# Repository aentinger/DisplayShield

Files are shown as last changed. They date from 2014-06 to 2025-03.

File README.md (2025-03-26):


💾 Display Shield
=================



# 📸 Image

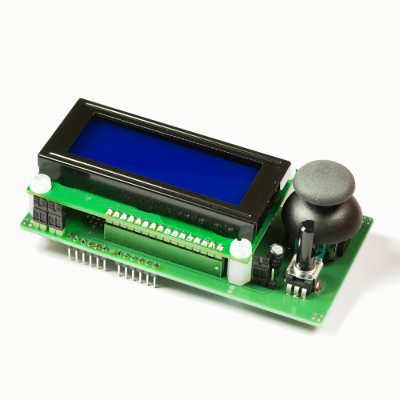
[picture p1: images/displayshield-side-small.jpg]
LXRobotics P10 DisplayShield


# 📂 Description

The LXRobotics Display Shield facilitates the easy control of a Liquid Crystal Display's with 4 rows and 20 columns. The control of the display is done via I2C - only two Arduino Pins are required. The contrast of LCD can be adjusted using a rotary potentiometer. A 2-axis joystick with integrated pushbutton can be used as input device. For a quick and easy start, an open source Arduino library with sample programs is available.

**Features**

* Large LCD (Liquid Crystal Display) with 4 rows und 20 columns [4x20] 
* LCD-font color: white
* LCD-background color: blue
* LCD included in scope of delivery
* Background illumination on/off switchable
* Display contrast is adjustable via a rotary potentiometer
* Control over I2C - only two Arduino-Pins are required (SDA, SCL)
* I2C-PullUp-Resistors can be connected via jumpers
* 2-axis joystick with integrated pushbutton
* Display Shield firmware is open source
* Microcontroller programmed with current firmware is included in assembly kit
* Display Shield Firmwareupdate via Arduino possible
* Arduino Library with example programs is available on GitHub

# 🎥 [Video](images/display_shield_demo.mp4)

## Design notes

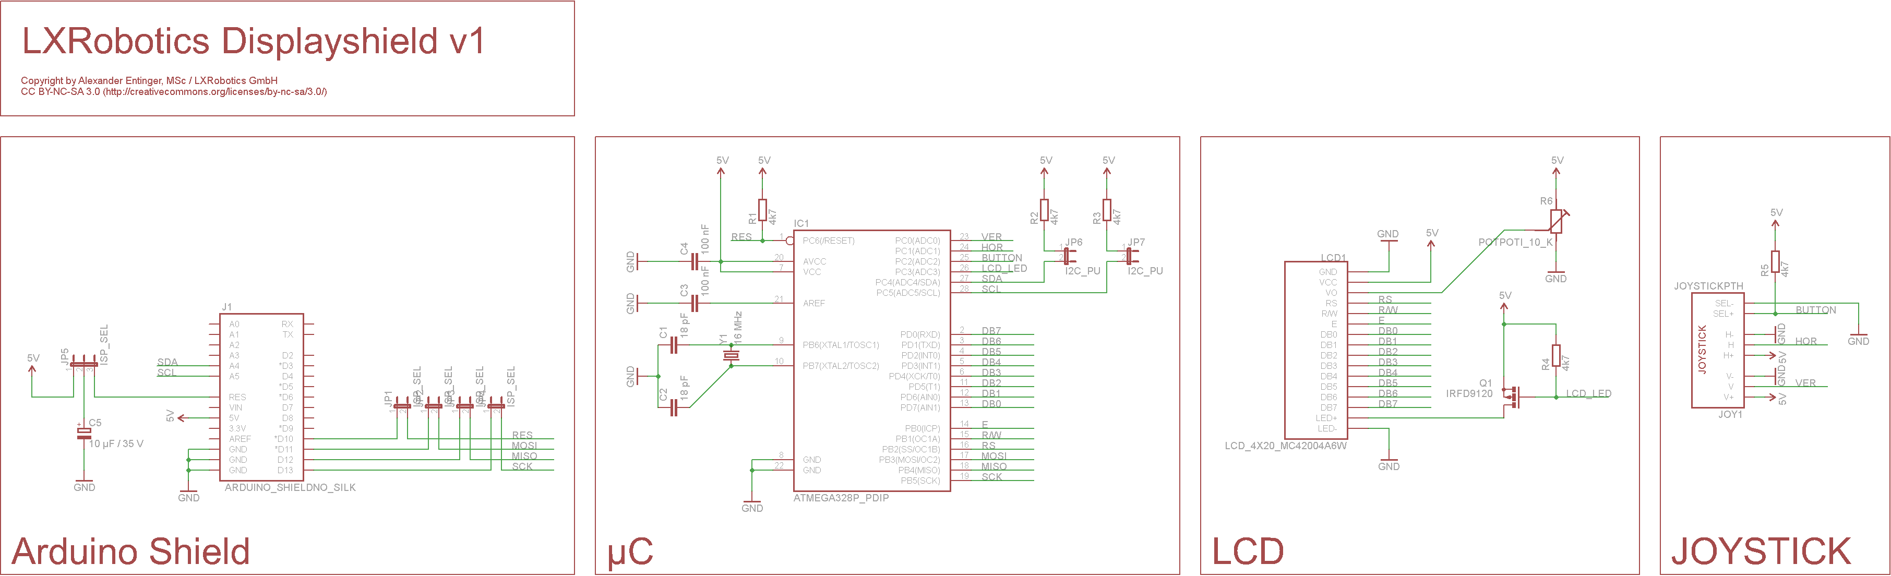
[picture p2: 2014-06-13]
hardware/lxr_display_shield_v1.png

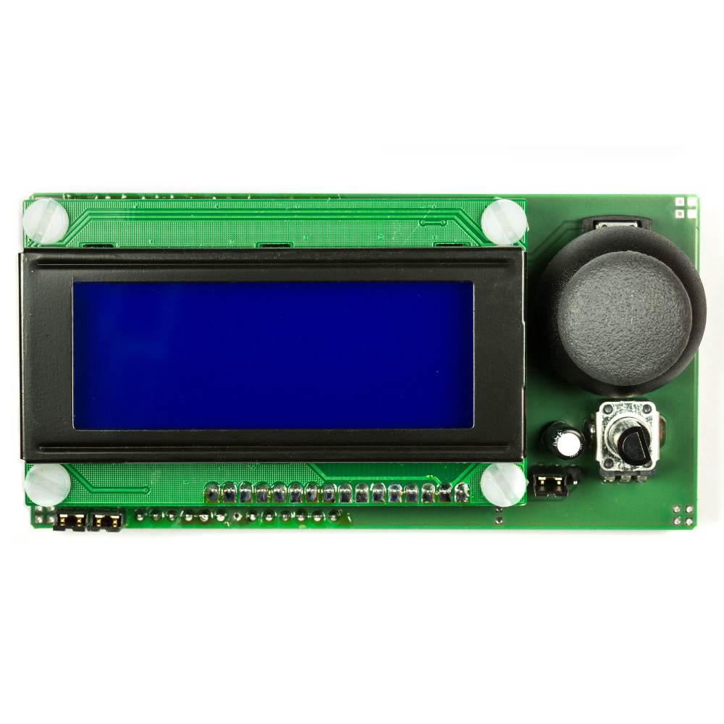
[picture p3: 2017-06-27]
images/displayshield-top-large.jpg

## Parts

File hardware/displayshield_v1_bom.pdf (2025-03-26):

Menge | Schaltplan | Bezeichnung | Farnell/Conrad Bestell Nummer | Preis (1 Stück) | Gesamtpreis | Wird bestückt | Footprint | Säckchen
1 | | LCD-Display, 4x20 | 2063162 | € 15,02 | € 15,02 | | | S1
1 | IC1 | ATMEGA328P, PDIP28 | 1715487 | € 3,11 | € 3,11 | | | S2
1 | | PDIP28 Sockel | 1103850 | € 1,15 | € 1,15 | | | S2
1 | Y1 | Quarz, 16 MHz, HC49 | 1611761 | € 0,23 | € 0,23 | | | S2
2 | C1,C2 | Kondensator, 18 pF, bedrahtet | 2332948 | € 0,34 | € 0,68 | | | S3
2 | C3,C4 | Kondensator, 100 nF, bedrahtet | 1216444 | € 0,10 | € 0,21 | | | S3
5 | R1,R2,R3,R4,R5 | Widerstand, bedrahtet, 4k7, 1/8 W | 1700245 | € 0,01 | € 0,05 | | | S3
6 | JP1,JP2,JP3,JP4,JP6,JP7 | Stiftleiste, 2 Polig, 2.54 mm | 3418285 | € 0,24 | € 1,44 | | | S4
7 | | Jumper, 2 Polig, 2.54 mm | 4218176 | € 0,14 | € 0,98 | | | S4
1 | C5 | Kondensator, 10µF, 35V, D 5mm, Raster 2 mm | 1236669 | € 0,07 | € 0,07 | | | S3
1 | JP5 | Stiftleiste, 3 Polig, 2.54 mm | 1022249 | € 0,19 | € 0,19 | | | S4
1 | Q1 | P-Kanal-MOSFET, DIL, IRFD9120 | 9103244 | € 1,21 | € 1,21 | | | S2
1 | JOY1 | Joystick, 2 Achsen | € | 3,40 | € | 3,40 | S1 | Kann auch von LXRobotics bereitgestellt werden | http://www.watterott.com/de/Thumb-Joystick - http://www.amazon.de/Buttons-Switches-Joysticks-COM-09032-Joystick/dp/B004QOOB10 - http://www.lipoly.de/index.php?main_page=product_info&products_id=103716 - http://www.hobbytronics.co.uk/thumb-joystick - https://www.sparkfun.com/products/9032
1 | | Stiftleiste, 1x16, 2.54 mm | 1248124 | € 1,51 | € 1,51 | S4
1 | LCD1 | Buchsenleiste, 1x16, 2.54 mm | 3419174 | € 1,51 | € 1,51 | S4
1 | R6 | Drehpotentiometer, 10k | 1191725 | € 2,79 | € 2,79 | S3
2 | J1 | Arduino Stiftleisten, 1x6, 2.54 mm | 1022255 | € 0,37 | € 0,74 | S4
2 | J1 | Arduino Stiftleisten, 1x8, 2.54 mm | 1022257 | € 0,19 | € 0,38 | S4
4 | Zylingerschraube, Nylon, M4 x 6 mm | 527678 | € | 0,04 | € | 0,15 | S5 | RS Components
4 | Nylon Sechskant Abstandshalter, M4 x M4, 10 mm | 382955 | € | 0,24 | € | 0,96 | S5 | RS Components
4 | Sechskantmutter, Nylon, M4 | 525717 | € | 0,10 | € | 0,42 | S5 | RS Components
1 | Leitfähiger Schaumstoff | 1687855 | € | 2,40 | € | 2,40 | - | Bestellung von 1 Stück für 50 Display Shields ausreichend
| | | Summe | | € | 38,59

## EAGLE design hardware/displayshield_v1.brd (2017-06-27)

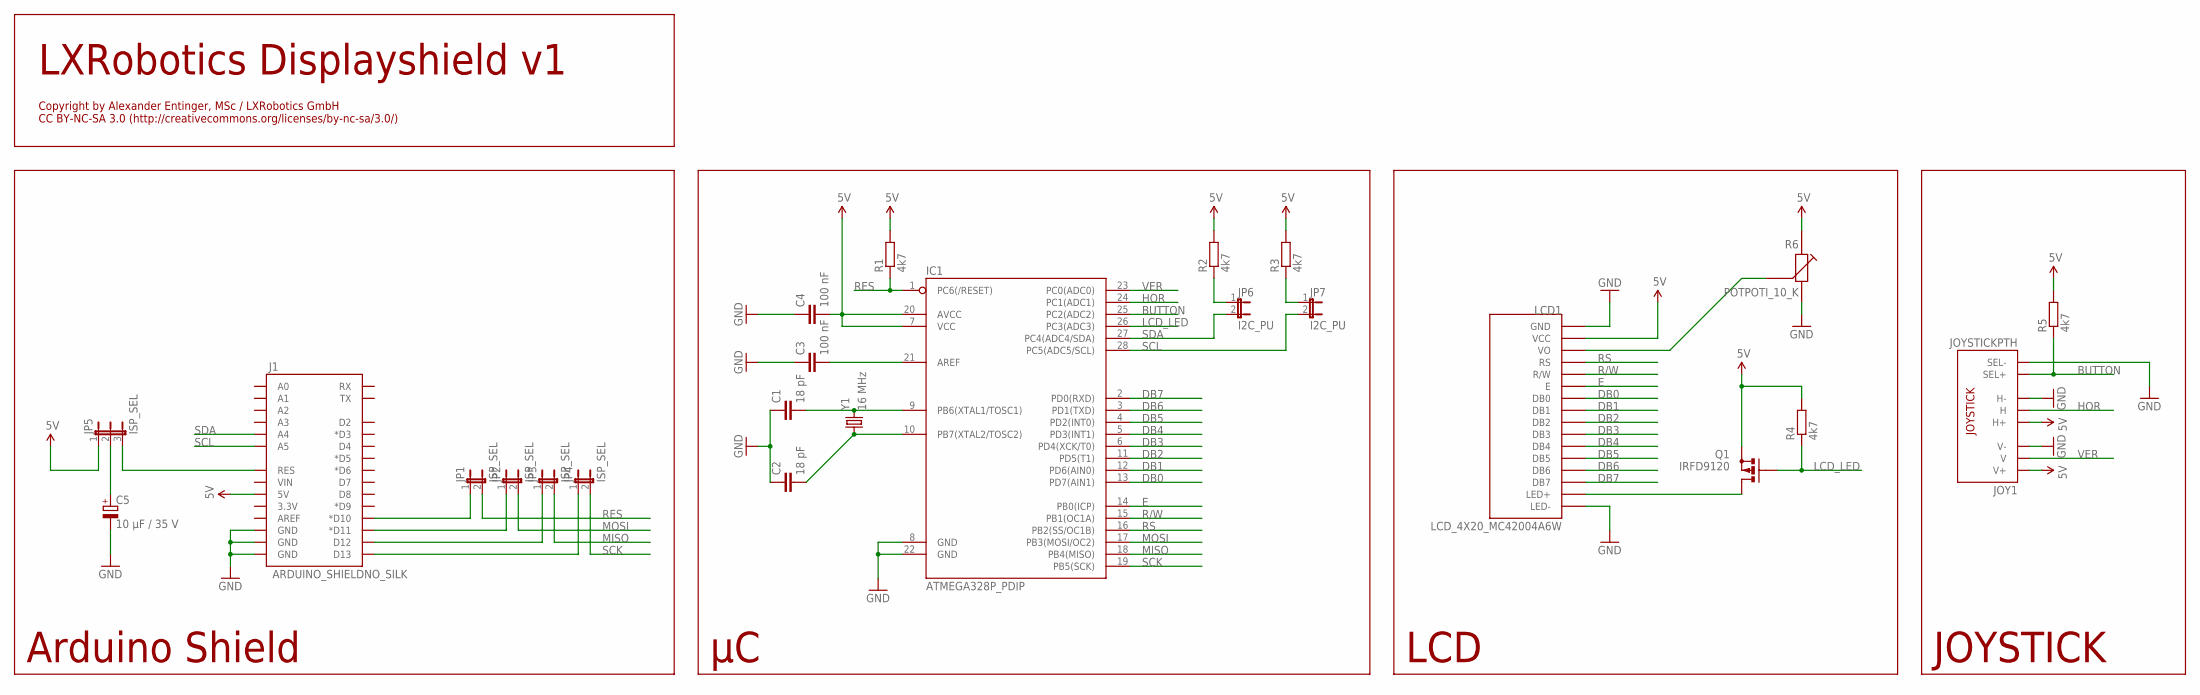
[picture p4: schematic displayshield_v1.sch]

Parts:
C1, C2: 18 pF; C025-025X050
C3, C4: 100 nF; C025-025X050
C5: 10 µF / 35 V; E2-5
IC1: ATMEGA328P_PDIP; DIL28-3
J1: ARDUINO_SHIELDNO_SILK; DUEMILANOVE_VIAS
JOY1: JOYSTICKPTH; JOYSTICK
JP1, JP2, JP3, JP4: ISP_SEL; JP1
JP5: ISP_SEL; JP2
JP6, JP7: I2C_PU; JP1
LCD1: LCD_4X20_MC42004A6W; LCD_3X40_MC42004A6W
Q1: IRFD9120; C370-01
R1, R2, R3, R4, R5: 4k7; 0204/5
R6: POTPOTI_10_K; POT_10K
Y1: 16 MHz; HC49US

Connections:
5V: C4.2, IC1.7 (VCC), IC1.20 (AVCC), J1.5V, JOY1.H1 (H+), JOY1.V1 (V+), JP5.1, LCD1.VCC, Q1.S, R1.2, R2.2, R3.2, R4.2, R5.2, R6.S
BUTTON: IC1.25 (PC2(ADC2)), JOY1.B1A (SEL+), R5.1
DB0: IC1.13 (PD7(AIN1)), LCD1.DB0
DB1: IC1.12 (PD6(AIN0)), LCD1.DB1
DB2: IC1.11 (PD5(T1)), LCD1.DB2
DB3: IC1.6 (PD4(XCK/T0)), LCD1.DB3
DB4: IC1.5 (PD3(INT1)), LCD1.DB4
DB5: IC1.4 (PD2(INT0)), LCD1.DB5
DB6: IC1.3 (PD1(TXD)), LCD1.DB6
DB7: IC1.2 (PD0(RXD)), LCD1.DB7
E: IC1.14 (PB0(ICP)), LCD1.E
GND: C1.1, C2.1, C3.1, C4.1, C5.-, IC1.8 (GND), IC1.22 (GND), J1.GND@0 (GND), J1.GND@1 (GND), J1.GND@2 (GND), JOY1.B2A (SEL-), JOY1.H3 (H-), JOY1.V3 (V-), LCD1.GND, LCD1.LED-, R6.E
HOR: IC1.24 (PC1(ADC1)), JOY1.H2 (H)
LCD_LED: IC1.26 (PC3(ADC3)), Q1.G, R4.1
MISO: IC1.18 (PB4(MISO)), JP3.2
MOSI: IC1.17 (PB3(MOSI/OC2)), JP2.2
unnamed: C2.2, IC1.10 (PB7(XTAL2/TOSC2)), Y1.1
unnamed: C1.2, IC1.9 (PB6(XTAL1/TOSC1)), Y1.2
unnamed: J1.D10 (*D10), JP1.1
unnamed: J1.D11 (*D11), JP2.1
unnamed: C3.2, IC1.21 (AREF)
unnamed: J1.D12, JP3.1
unnamed: J1.D13, JP4.1
unnamed: C5.+, JP5.2
unnamed: LCD1.LED+, Q1.D, Q1.D1 (D)
unnamed: LCD1.VO, R6.VAR
unnamed: J1.RES, JP5.3
unnamed: JP6.1, R2.1
unnamed: JP7.1, R3.1
R/W: IC1.15 (PB1(OC1A)), LCD1.R/W
RES: IC1.1 (PC6(/RESET)), JP1.2, R1.1
RS: IC1.16 (PB2(SS/OC1B)), LCD1.RS
SCK: IC1.19 (PB5(SCK)), JP4.2
SCL: IC1.28 (PC5(ADC5/SCL)), J1.A5, JP7.2
SDA: IC1.27 (PC4(ADC4/SDA)), J1.A4, JP6.2
VER: IC1.23 (PC0(ADC0)), JOY1.V2 (V)

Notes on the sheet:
Arduino Shield
LCD
JOYSTICK
Copyright by Alexander Entinger, MSc / LXRobotics GmbH CC BY-NC-SA 3.0 (http://creativecommons.org/licenses/by-nc-sa/3.0/)
LXRobotics Displayshield v1

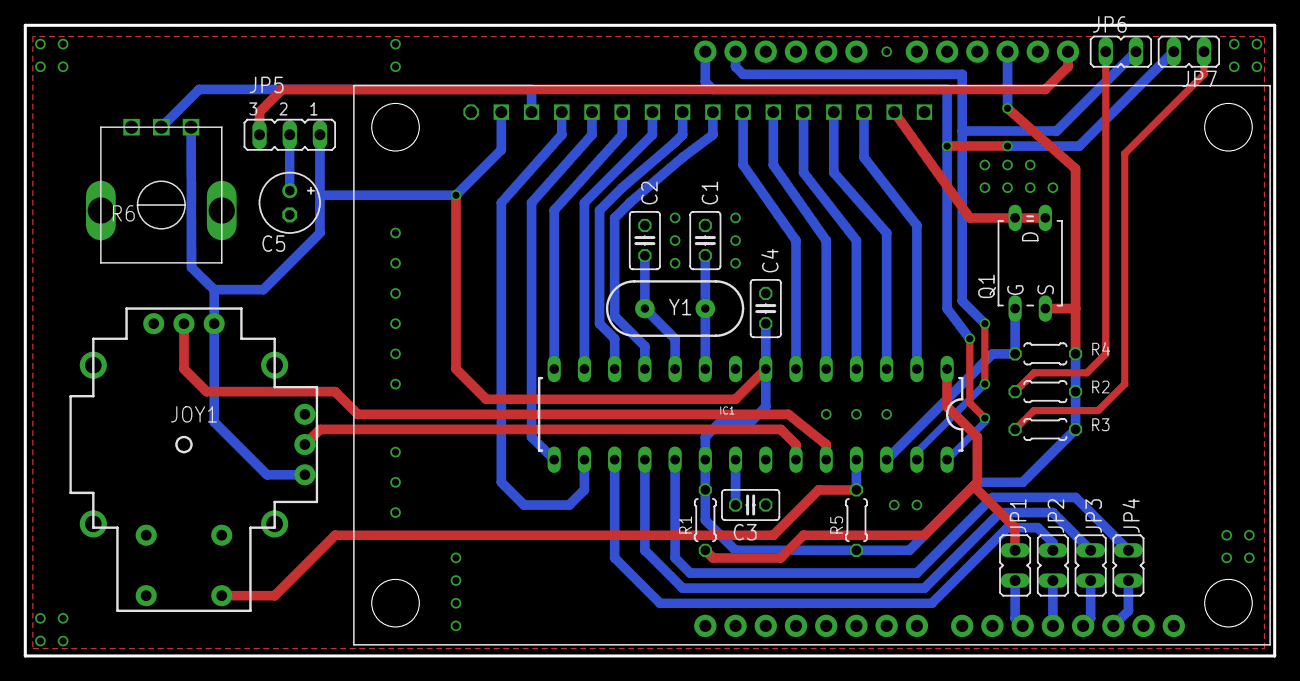
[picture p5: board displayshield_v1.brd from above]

Board: 2 copper layers, 105.0 x 53.0 mm, 24 parts (0 on the bottom side), 36 nets.

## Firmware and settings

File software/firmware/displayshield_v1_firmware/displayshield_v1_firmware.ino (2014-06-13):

/**
 * @author Alexander Entinger, MSc / LXRobotics
 * @brief this sketch implements the firmware stored on the ATMEGA328P microprocessor of the LXRobotics Displayshield and allows an I2C Control of the 4 line lcd screen
 * @file displayshield_v1_firmware.ino
 * @license Attribution-NonCommercial-ShareAlike 3.0 Unported (CC BY-NC-SA 3.0) ( http://creativecommons.org/licenses/by-nc-sa/3.0/ )
 */

/* INCLUDE SECTION */
#include <LiquidCrystal.h>
#include <Wire.h>

#include "lcd.h"
#include "joystick.h"

/* I2C SLAVE PROPERTIES */
static int const I2C_SLAVE_ADDRESS = 40;
/* VERSION PROPERTIES */
static byte const HW_VERSION = 1;
static byte const SW_VERSION = 1;

/* FUNCTION SECTION */

void setup() {
  // init lcd
  lcd::begin();
  // init joystick
  joystick::begin();  
  // init i2c library
  Wire.onReceive(i2c_data_received_callback);
  Wire.onRequest(i2c_data_request_callback);
  Wire.begin(I2C_SLAVE_ADDRESS);
}

void loop() {
  // update display
  lcd::update();
  // update the joystick data
  joystick::update();
}

/* I2C INTERFACE */
// I2C Register Description
// READ
// REG 0 R -> HW Version (Upper 4 Bit), Software Version (Lower 4 Bit)
// REG 1 R -> Joystick Horizontal
// REG 2 R -> Joystick Vertical
// REG 3 R -> Bit 0 = 1 => Button pressed since last readout
//       R -> Bit 1 = 0 => Button not pressed since last readout
// WRITE
// REG 0 W -> Bit 0 = 1 => Backlight activated
//       W -> Bit 0 = 0 => Backlight deactivated
// REG 1 W -> LCD LINE 1
// REG 2 W -> LCD LINE 2
// REG 3 W -> LCD LINE 3
// REG 4 W -> LCD LINE 4

void i2c_data_received_callback(int number_of_bytes) {

  // parse the data
  for(int i=0; i<number_of_bytes; i++) {
    parse_i2c(Wire.read()); 
  }
}

void parse_i2c(char const data) {

  typedef enum {
    E_REG_ADDR, E_DATA, E_ERROR  } 
  E_PARSE_STATE;
  static E_PARSE_STATE state = E_REG_ADDR;
  static byte reg_addr = 0xFF;
  static char row_buf[21];
  static byte row_buf_cnt = 0;

  switch(state) {
  case E_REG_ADDR: 
    {
      reg_addr = data;
      state = E_DATA;
    } 
    break;
  case E_DATA: 
    {
      switch(reg_addr) {
      case 0x00: 
        {
          if(data == 0x01) lcd::set_backlight(lcd::BACKLIGHT_ON);
          else if(data == 0x00) lcd::set_backlight(lcd::BACKLIGHT_OFF);
          state = E_REG_ADDR;
        } 
        break;
      case 0x01: 
      case 0x02:
      case 0x03:
      case 0x04:
        {
          row_buf[row_buf_cnt] = data; 
          row_buf_cnt++;
          if(data == 0x00) {
            lcd::print(reg_addr-1, row_buf);
            row_buf_cnt = 0;
            state = E_REG_ADDR;
          }
        } break;
      default: 
        {
          state = E_ERROR;
        } 
        break;
      }
    } 
    break;
  case E_ERROR: 
    {
      for(;;) {
        lcd::set_backlight(lcd::BACKLIGHT_TOOGLE);
        delay(100);
      }
    } 
    break;
  default: 
    {
      state = E_ERROR;
    } 
    break;
  }
}

void i2c_data_request_callback() {
    byte tx_buf[4] = {0};
    joystick::s_data const joy_data = joystick::get_data();
    // version
    tx_buf[0] = (HW_VERSION<<4) + SW_VERSION;
    // joystick hor
    tx_buf[1] = joy_data.x;
    // joystick ver
    tx_buf[2] = joy_data.y;  
    // button state
    joy_data.button_was_pressed ? tx_buf[3] = 1 : tx_buf[3] = 0;
    // send answer
    Wire.write(tx_buf, 4);
}

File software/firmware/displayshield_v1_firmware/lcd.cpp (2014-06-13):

/**
 * @author Alexander Entinger, MSc / LXRobotics
 * @brief this module encapsulates the control of the lcd attached to the LXRobotics Display Shield
 * @file lcd.cpp
 * @license Attribution-NonCommercial-ShareAlike 3.0 Unported (CC BY-NC-SA 3.0) ( http://creativecommons.org/licenses/by-nc-sa/3.0/ )
 */

/* INCLUDE SECTION */

#include "lcd.h"
#include <LiquidCrystal.h>

/* DEFINE SECTION */

/* LCD BACKLIGHT */
// LCD_LED = PC3 = A3
#define LCD_LED_DDR     DDRC
#define LCD_LED_PORT    PORTC
#define LCD_LED         (1<<3)

/* CONSTANT SECTION */

/* LCD PROPERTIES */
// RS = PB2 = 10
static int const rs = 10;
// RW = PB1 = 9
static int const rw = 9;
// enable = PB0 = 8
static int const enable = 8;
// d0 = PD7 = 7
static int const d0 = 7;
static int const d1 = 6;
static int const d2 = 5;
static int const d3 = 4;
static int const d4 = 3;
static int const d5 = 2;
static int const d6 = 1;
// d7 = PD0 = 0
static int const d7 = 0;
// number of rows and cols of the lcd display
static int const LCD_COLS = 20;
static int const LCD_ROWS = 4;

/* GLOBAL VARIABLE SECTION */

LiquidCrystal my_lcd(rs,rw,enable,d0,d1,d2,d3,d4,d5,d6,d7);
static char display_content[LCD_ROWS][LCD_COLS];

/* CODE SECTION */

/**
 * @brief initializes the module
 */
void lcd::begin() {
  my_lcd.begin(LCD_COLS, LCD_ROWS);
  for(int r=0; r<LCD_ROWS; r++)
    for(int c=0; c<LCD_COLS; c++) display_content[r][c] = ' ';
  lcd::update();
  
  // set backlight to output and turn it off  
  LCD_LED_DDR |= LCD_LED;
  lcd::set_backlight(BACKLIGHT_OFF);
}

/**
 * @brief writes the content of line_content into the display buffer for row 'row'
 */
void lcd::print(unsigned int const row, char *line_content) {
  if(row > (LCD_ROWS-1)) return;
  int const length = strlen(line_content);
  for(int c=0; c<LCD_COLS; c++) {
    if(c < length)
      display_content[row][c] = line_content[c];
    else
      display_content[row][c] = ' ';
  }
}

/**
 * @brief writes any changes done by the write function onto the display
 */
void lcd::update() {
  for(int r=0; r<LCD_ROWS; r++) {
    my_lcd.setCursor(0,r);
    for(int c=0; c<LCD_COLS; c++) my_lcd.write(display_content[r][c]);
  }
}

/**
 * @brief control the lcd backlight
 */
void lcd::set_backlight(E_BACKLIGHT_STATUS const stat) {
  switch(stat) {
   case BACKLIGHT_ON: LCD_LED_PORT &= ~LCD_LED; break;
   case BACKLIGHT_OFF: LCD_LED_PORT |= LCD_LED; break;
   case BACKLIGHT_TOOGLE: LCD_LED_PORT ^= LCD_LED; break;
   default: break; 
  }
}

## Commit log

2017-06-27 Adding hardware + images
    [displayshield_v1.brd, displayshield_v1.sch]
2025-03-26 Add BOM.

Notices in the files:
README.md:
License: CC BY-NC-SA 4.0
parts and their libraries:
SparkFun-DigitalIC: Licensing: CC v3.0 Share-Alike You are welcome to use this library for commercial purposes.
